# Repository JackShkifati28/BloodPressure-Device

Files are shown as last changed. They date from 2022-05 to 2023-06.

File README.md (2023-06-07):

# **Blood Pressure Machine**

This is a C application created for the Adafruit Playground Classic that makes use of the Arduino framework. A dynamic, 
interactive software that uses data from a Honeywell pressure sensor to detect the user's heart rate, as well as systolic 
and diastolic blood pressure.

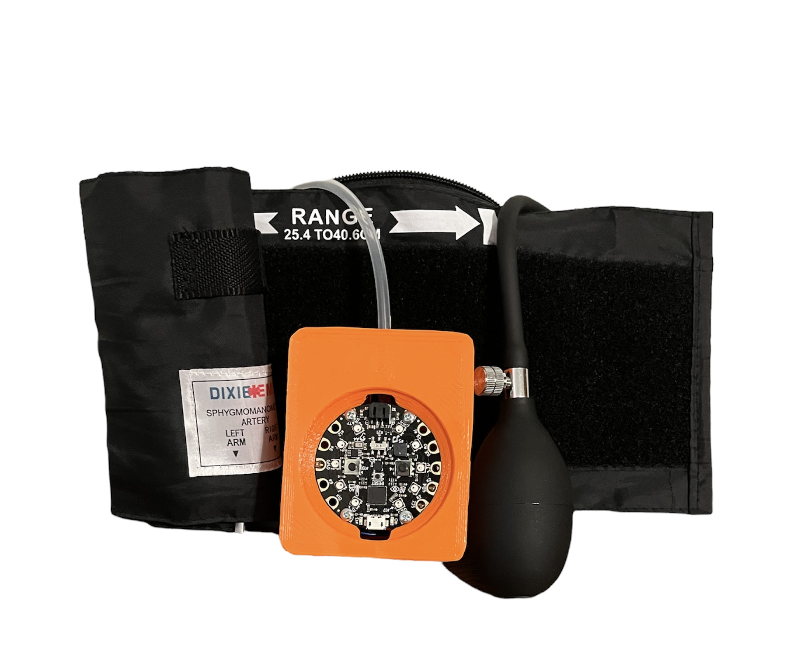
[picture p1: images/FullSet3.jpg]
My Image


## **Project Development**

### **Case Development**
1. **Agenda**

   The case was developed as an extension to the main "The Pressure is On" project agenda. I rapid-prototyped a 3D-printable boxcase that would hold the Adafruit Circuit Playground Classic microcontroller, the Honeywell MPRLS0300YG00001BB  pressure sensor, and cables and other electrical components required to transform the blood pressure sensing device into a prototype of a robust, portable solution. In the design's final iteration, the case holds all the wiring needed for the device's operation, and only needs the user to connect a USB cable to the exposed USB port on the Playground microcontroller.

2. **Design Process**

   As a basis for the case design, the official Shape Edition square case by Adafruit was used. [Find the design here](https://www.thingiverse.com/thing:2585702). The design was chosen because it allowed for the easiest expansion to accommodate rectangular electronic components, such as the Honeywell pressure sensor.

3. **Possible Future Evolution**

   Possibly the largest single improvement that could be done to the case itself with better manufacturing capability is selectively covering parts of the board other than neopixels required to communicate with the user. Furthermore, if we were to commercialize the product, it could be worth it to use alternative clamping mechanism for attaching the leads to the Playground, for example conductive rings screwed to the Playground with screws and nuts.

## **User Interface and Operation**
___

To operate the machine, follow the steps below:

1. Rest the patient's arm on a level surface in line with their heart.
2. Position the stethoscope over the brachial artery, found in the bend of the elbow, and listen for the pulse
3. Slowly inflate the cuff and listen for when the pulse disappears. This is your cue to stop inflating the cuff. At this point, a blinking pink light would begin flashing.

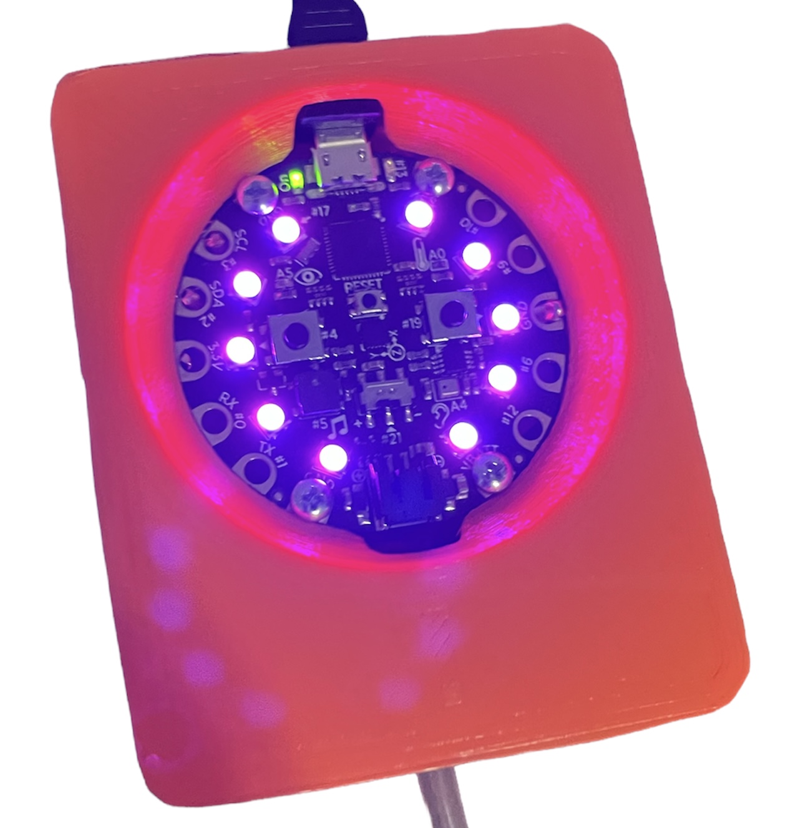
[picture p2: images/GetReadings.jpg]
My Image
   

4. Calibration will take place. The machine uses Neo pixels to inform the user when the brachial artery's circulation is cut off, and ensures that the cuff deflation rate remains at the recommended 2-3mmhg per second, as per the American Hospital Association (AHA).
  
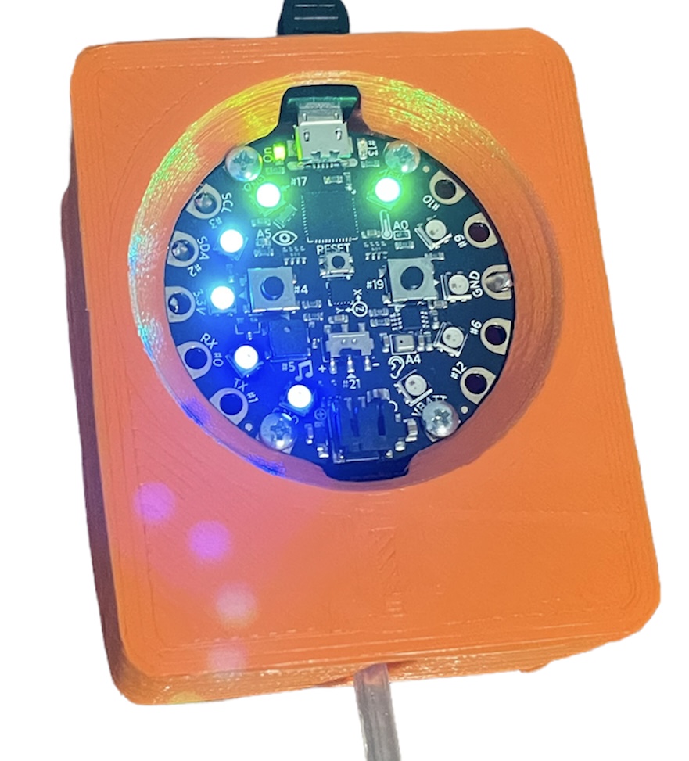
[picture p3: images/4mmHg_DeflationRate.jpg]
My Image
  

5. When the measurement is complete, a white light from the LEDs will begin to flicker.
  
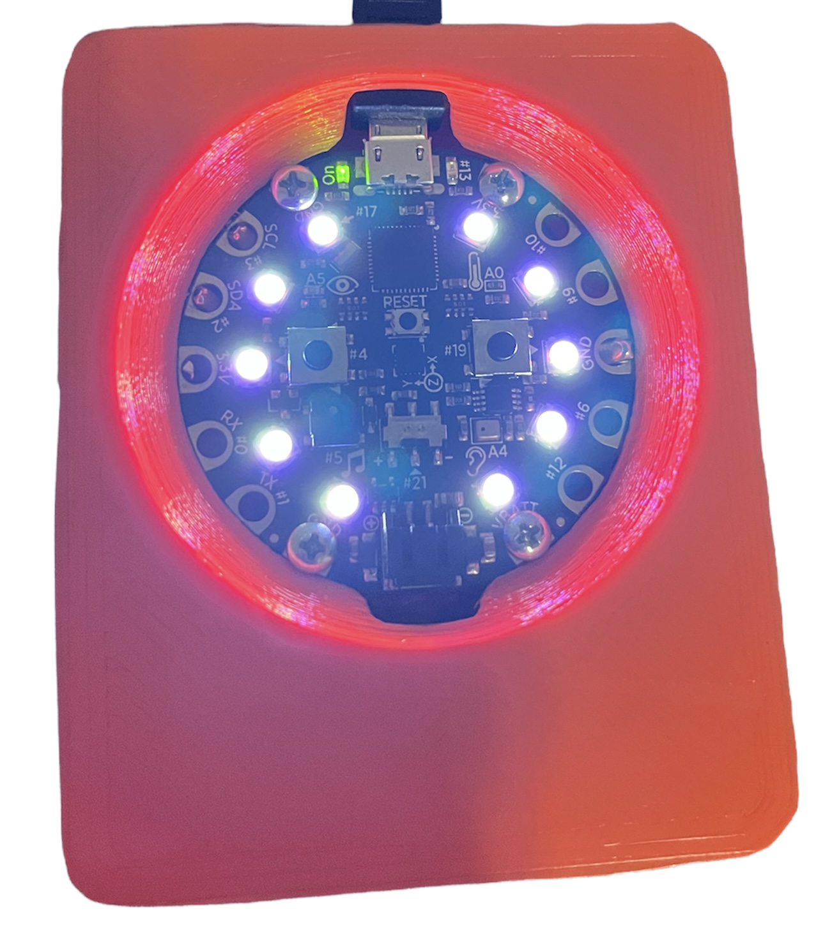
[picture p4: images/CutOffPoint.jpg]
My Image
  

6. Finally, the results – heart rate, systolic and diastolic blood pressure – are displayed on the screen.

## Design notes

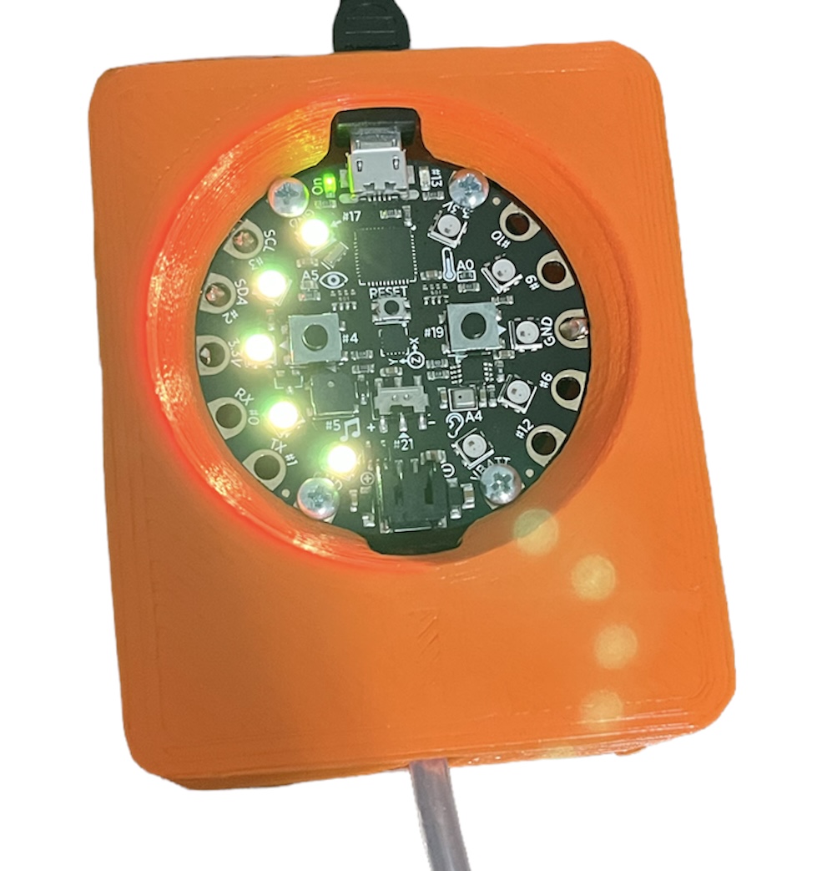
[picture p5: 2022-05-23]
images/PressureBar.jpg

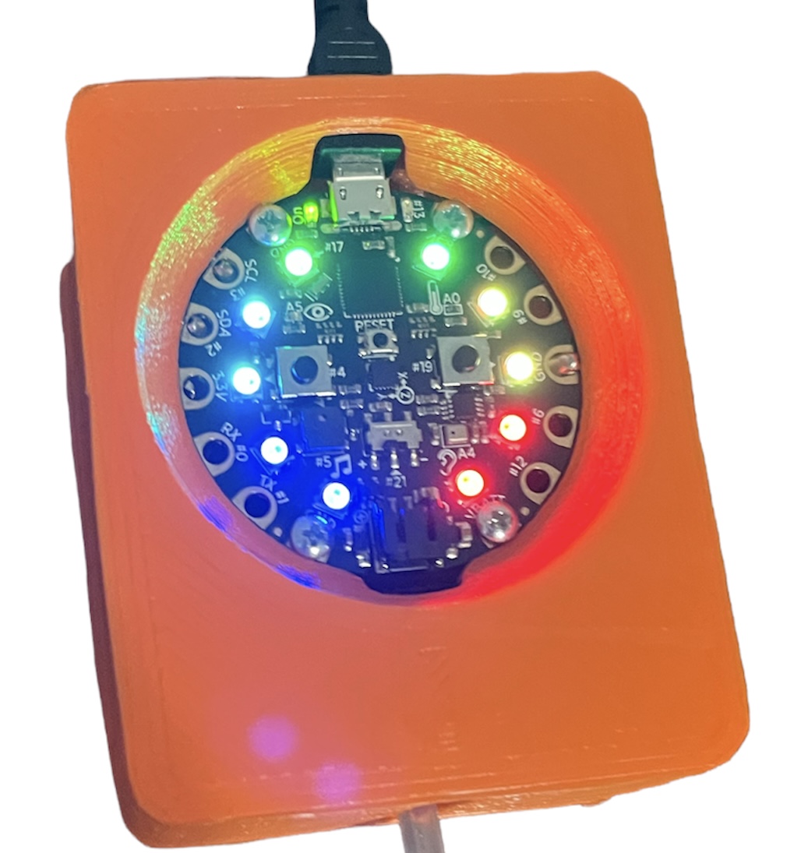
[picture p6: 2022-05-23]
images/HighDeflationRate.jpg

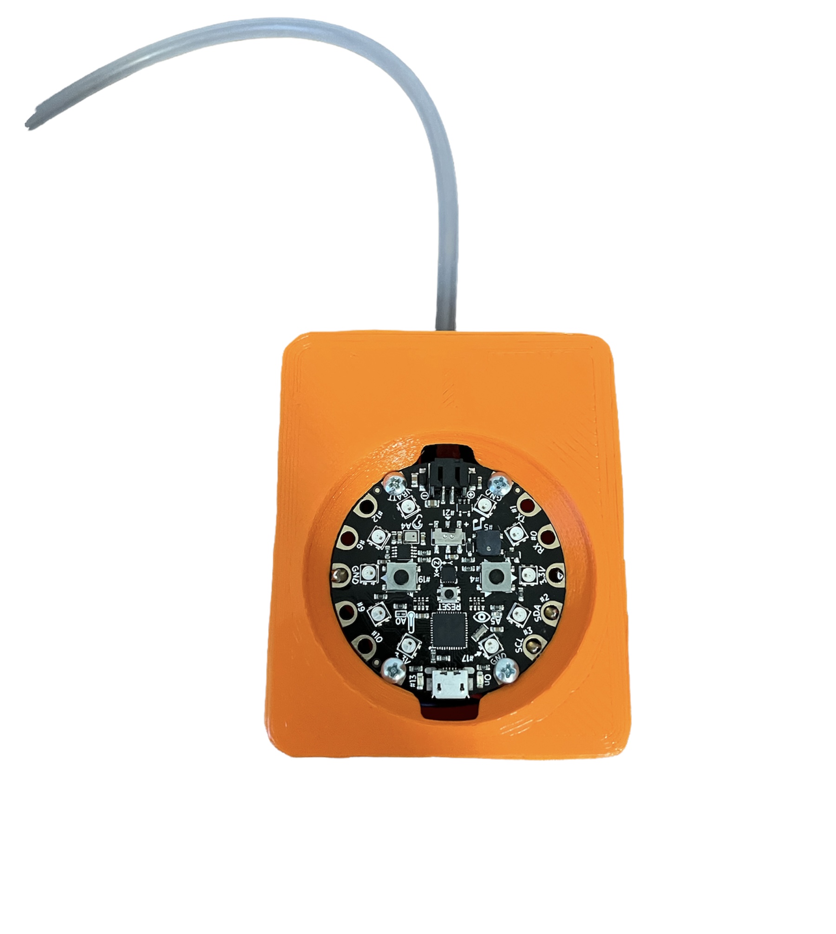
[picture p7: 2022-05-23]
images/Outercase.jpg

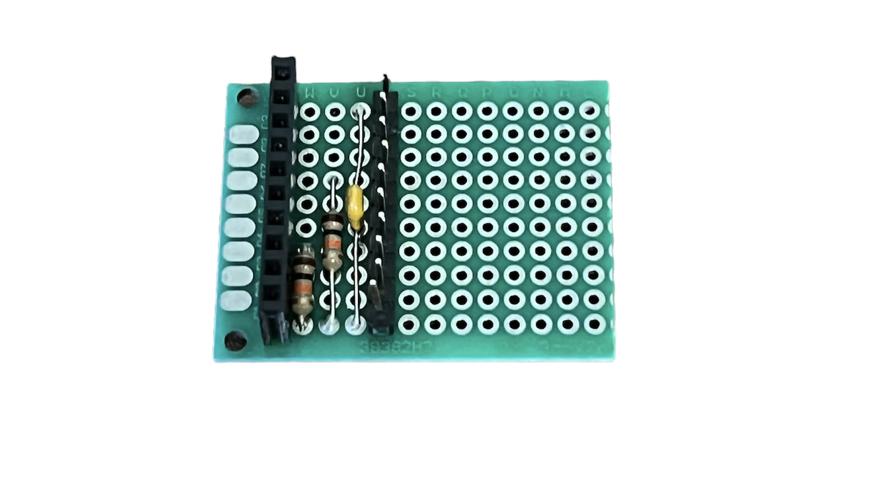
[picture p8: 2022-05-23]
images/Prototype_Board.jpg

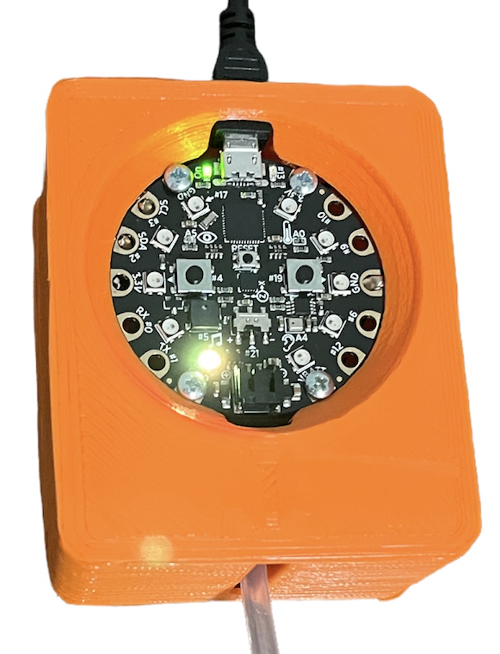
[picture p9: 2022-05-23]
images/StarterBar.jpg

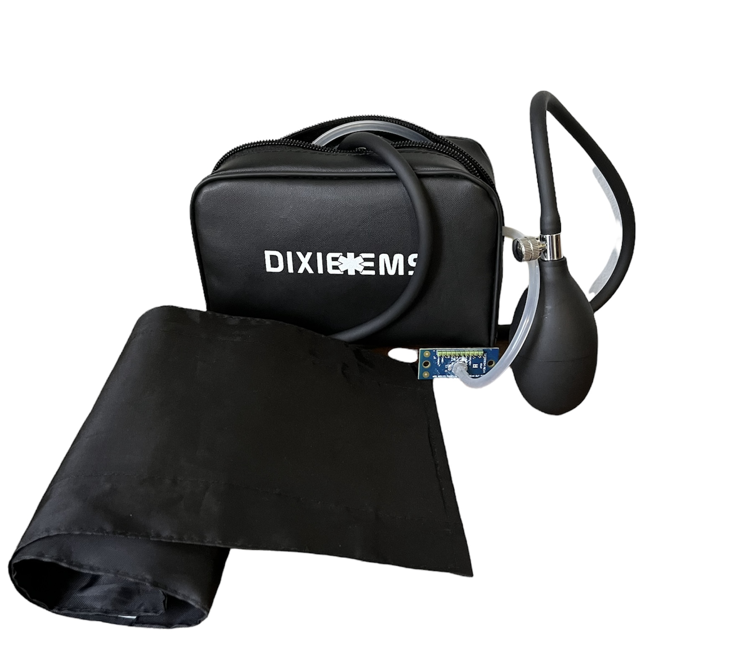
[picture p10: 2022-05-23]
images/Sensor&Cuff.jpg

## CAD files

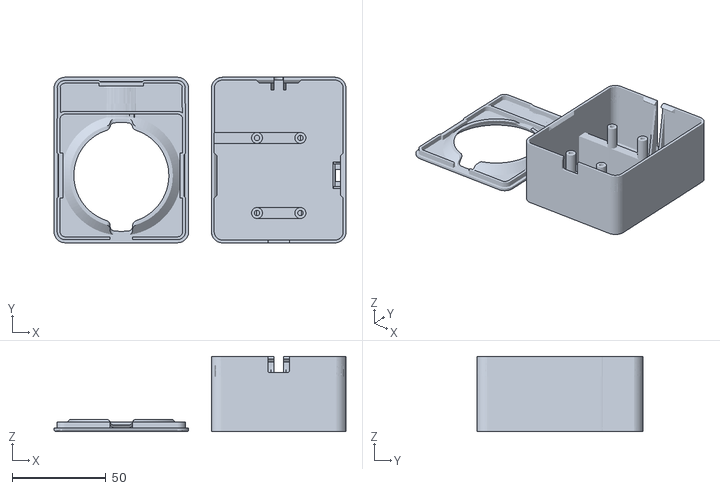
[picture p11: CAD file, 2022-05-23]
3D-Files/pressure_sensor_case.stl
156.1 x 88.5 x 40.1

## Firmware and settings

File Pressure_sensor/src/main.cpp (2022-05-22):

// ECE-UY 3144/4144 Introduction to Embedded Systems Design
// Professor Matthew S. Campisi
// Final Project "The Pressure is On"
// Bartosz Bieńkowski, Juan Jose, Jack Shkifati

// YouTube link: https://youtu.be/qNyu2ac87pc

/*
         _   _ ________  ___ _____  ____________ _____ _____ _____ _   _______ _____ 
   ____ | | | |  _  |  \/  ||  ___| | ___ \ ___ \  ___/  ___/  ___| | | | ___ \  ___|
  / __ \| |_| | | | | .  . || |__   | |_/ / |_/ / |__ \ `--.\ `--.| | | | |_/ / |__  
 / / _` |  _  | | | | |\/| ||  __|  |  __/|    /|  __| `--. \`--. \ | | |    /|  __| 
| | (_| | | | \ \_/ / |  | || |___  | |   | |\ \| |___/\__/ /\__/ / |_| | |\ \| |___ 
 \ \__,_\_| |_/\___/\_|  |_/\____/  \_|   \_| \_\____/\____/\____/ \___/\_| \_\____/ 
  \____/                                                                             
                                                                                    
*/

// Note: we have a miscalibrated sensor that reports 18 mmHg when at atmospherpic pressure.
// Our code is written to account for this deviation.

#include <Arduino.h>
#include "Wire.h"
#include <Adafruit_CircuitPlayground.h>

#define Pressure 0x18
#define Output_Measurement 0xAA
#define exit 0x00
#define Pressure_Min 0
#define Pressure_Max 300
#define Output_Min 419430
#define Output_Max 3774873

uint8_t stage;
float readings[10];
uint8_t readingsIdx = 0;
unsigned short timeAtStage3 = 0;

float last20Pressures[20]; // Array used for deflation rate
int last20PressuresIdx = 0;
float currPressure, prevPressure, slope;

// final vales to be found
float systolic, diastolic, maxDifference;
float maxPeak = 0;
float strongestHeartbeat, heartRate;
bool systolicFound = false; // switch to true when first heartbeat detected
float pressureBottomBeat, pressureTopPeak;

// used to calculate the biggest heartbeat
bool goingUp = false;

// helper variables for calculating the heart rate
int heartBeatCounter;
int timeForHeartRate;

float readPressure(){
  uint32_t value = 0;
  Wire.beginTransmission(Pressure);

  Wire.write(Output_Measurement);
  Wire.write(exit);
  Wire.write(exit);

  Wire.endTransmission(false);
  delay(5);

  Wire.requestFrom(Pressure, 4, true);

  if (Wire.available())
  {
    int status = Wire.read(); // read status byte
    
    // verify status byte
    if(status & (1<<5)){
      Serial.println("device is busy");
      return -1;
    }
    else if (!(status & (1<<6))){
      Serial.println("device has no power");
      return -2;
    }
    else if (status & (1<<2)){
      Serial.println("bad memory");
      return -3;
    }
    else if(status & (1<<0)){
      Serial.println("saturated");
      return -4;
    }
    
    // read raw pressure data
    value |= ((uint32_t)Wire.read()<<16);
    value |= ((uint32_t)Wire.read()<<8);
    value |= (Wire.read()<<0);
    readings[readingsIdx] = value;

    if(value >= 0){
      float realPressure = (float)(value - Output_Min) * ((float)Pressure_Max - (float)Pressure_Min)/((float)Output_Max - (float)Output_Min) + Pressure_Min;
      readings[readingsIdx] = realPressure;
      readingsIdx++;
      if(readingsIdx >= 10) readingsIdx = 0;
      return realPressure;
    }
  }
  return (float)value;
}

// set the appropriate number of LEDs to yellow depending on current pressure to use while pumping
void pumpingBar(float pressurePumped){
  CircuitPlayground.clearPixels();
  CircuitPlayground.setPixelColor(4, 0xFFFF00);
  if (pressurePumped > 40){
    CircuitPlayground.setPixelColor(3,0xFFFF00);
    if (pressurePumped > 55){
      CircuitPlayground.setPixelColor(2,0xFFFF00);
      if (pressurePumped > 70){
        CircuitPlayground.setPixelColor(1,0xFFFF00);
        if (pressurePumped > 85){
          CircuitPlayground.setPixelColor(0,0xFFFF00);
          if (pressurePumped > 100){
            CircuitPlayground.setPixelColor(9,0xFFFF00);
            if (pressurePumped > 115){
              CircuitPlayground.setPixelColor(8,0xFFFF00);
              if (pressurePumped > 130){
                CircuitPlayground.setPixelColor(7,0xFFFF00);
                if (pressurePumped > 145){
                  CircuitPlayground.setPixelColor(6,0xFFFF00);
                  if (pressurePumped > 160) CircuitPlayground.setPixelColor(5,0xFFFF00);
                }
              }
            }
          }
        }
      }
    }
  }
}

// set the appropriate number of LEDs depending on current deflation rate, to let the user dynamically adjust the valve
void slopeBar(float decreaseRate){
  CircuitPlayground.clearPixels();
  CircuitPlayground.setPixelColor(4,0x0000FF);
  if (decreaseRate > 0.5){
    CircuitPlayground.setPixelColor(3,0x0000FF);
    if (decreaseRate > 1){
      CircuitPlayground.setPixelColor(2,0x007F7F);
      if (decreaseRate > 2){
        CircuitPlayground.setPixelColor(1,0x007F7F);
        if (decreaseRate > 3){
          CircuitPlayground.setPixelColor(0,0x00FF00);
          if (decreaseRate > 4){
            CircuitPlayground.setPixelColor(9,0x00FF00);
            if (decreaseRate > 5){
              CircuitPlayground.setPixelColor(8,0x7F7F00);
              if (decreaseRate > 6){
                CircuitPlayground.setPixelColor(7,0x7F7F00);
                if (decreaseRate > 6.5){
                  CircuitPlayground.setPixelColor(6,0xFF0000);
                  if (decreaseRate > 7) CircuitPlayground.setPixelColor(5,0xFF0000);
                }
              }
            }
          }
        }
      }
    }
  }
}

// Calculates the deflation rate and light up neo pixels accordingly
void deflationRate(float currPressure){
  float prevPressure = last20Pressures[(last20PressuresIdx+1)%20];
  slopeBar(abs(currPressure - prevPressure));
  last20Pressures[last20PressuresIdx] = currPressure;
  last20PressuresIdx = (last20PressuresIdx + 1) % 20;
}

void setup(){
  Serial.begin(9600);
  Wire.begin();
  CircuitPlayground.begin();
  stage = 1;
  CircuitPlayground.setPixelColor(4, 0xFFFF00);
}

void loop(){
  currPressure = readPressure(); // read pressure from the sensor
  delay(45); // additional 5 miliseconds for processing

  // PRE-PUMPING STAGE
  if((stage == 1) && (currPressure > 30)) stage = 2;

  // PUMPING STAGE
  else if((stage == 2)){
    pumpingBar(currPressure); // set LEDs to indicate progress
    if(currPressure > 170){ // required pressure reached
      for(int x = 0; x < 10; x++) CircuitPlayground.setPixelColor(x, 0xFFFFFF); // set the LEDs to white to let the user stop pumping
      stage = 3; // move to stage 3
    }
  }

  // PRE-DEFLATION STAGE
  else if(stage == 3){
    // prime the last20Pressures array for stage 4
    last20Pressures[last20PressuresIdx] = currPressure;
    last20PressuresIdx = (last20PressuresIdx + 1) % 20;
    
    // if two seconds in stage 3 have passed, prepare for stage 4 and move to it
    if(timeAtStage3 > 40){
      timeAtStage3 = 0; // make sure the timer is zeroed-out for the next user
      prevPressure = currPressure; // save current pressure to prevPressure
      heartBeatCounter = 0;
      timeForHeartRate = 0;
      maxDifference = 0;
      stage = 4; // move to stage 4
    }

    timeAtStage3++;
  }

  // DEFLATION AND MEASUREMENT STAGE
  else if(stage == 4){
    deflationRate(currPressure);
    float slope = (currPressure - prevPressure);
    
    //Before systolic is found, no need to worry about detecting heartbeats
    if(systolicFound){
      //This is the end of a heartbeat
      if(goingUp && (slope < 0)){
        pressureTopPeak = currPressure;
        if(((pressureTopPeak - pressureBottomBeat) > maxDifference) && (currPressure <= 70)){
          //Start accounting for biggest heartbeat below 70 mmHg, the measurement is unreliable if the data is captured earlier
          maxDifference = pressureTopPeak - pressureBottomBeat;
          maxPeak = currPressure;
        }
        else strongestHeartbeat = maxPeak;
        goingUp = false;
      }
      //This means that a new heartbeat was detected
      else if(!goingUp && (slope > 0)){
        pressureBottomBeat = currPressure;
        goingUp = true;
        heartBeatCounter++;
      }
      timeForHeartRate++;
    }

    //The program enters this if statement when the first heartbeat/systolic is found
    if((slope > 0) && (!systolicFound)){
      systolic = currPressure * 0.85; // coefficient determined experimentally
      systolicFound = true;
      goingUp = true;
      pressureBottomBeat = currPressure;
      heartBeatCounter++;
    }

    prevPressure = currPressure;

    // set all LEDs to pink to signal end of measurement, progress to data communication stage
    if(currPressure < 50){
      for(uint8_t i = 0; i < 10; i++) CircuitPlayground.setPixelColor(i, 0xFF00FF);
      stage = 5;
    }
  }

  // DATA COMMUNICATION STAGE
  else if(stage == 5){
    Serial.print("Your systolic is ");
    Serial.println(systolic);
    diastolic = systolic - strongestHeartbeat;
    Serial.print("Your diastolic is ");
    Serial.println(diastolic);
    float heartRate = heartBeatCounter / (timeForHeartRate*0.0009); //Multiply the time by 0.0009 because it's in milliseconds, compensated for processing delays
    Serial.print("Your heart rate is ");
    Serial.println(heartRate);
    delay(10000);

    // return to stage 1 for device reuse
    CircuitPlayground.clearPixels();
    CircuitPlayground.setPixelColor(4, 0xFFFF00);
    stage = 1;
  }
}
